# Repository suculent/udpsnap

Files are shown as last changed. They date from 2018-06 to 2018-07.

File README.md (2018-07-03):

# UDP Snap

[See video](https://www.youtube.com/watch?v=fNixYq2eqGM&feature=youtu.be&a=)

Aim of this project is to provide iOS camera capture triggered by UDP commands from remote device.
In this example an ESP-8266 based rotary pad with H-L293N bridge, HS17 servo and some 3D printed parts.

## ESP8266

App for ESP8266 controls servo by advancing given steps in given interval, which is not exact in order to prevent vibrations.
Posts notifications on steps, so the iOS camera knows when is the right time to capture numbered step.

## iOS

* Minimal app in Swift 4 for iOS 11+, features latest photo capture APIs and server built on IBM's BlueSocket framework.
* App starts UDP server and performs camera capture directly to iCloud drive Documents when notified by ESP8266 client.
* UDP commands are received over WiFi from device acquired over MDNS on the same network.
* The communication is bi-directional, sending following commands: `PLAY`, `STOP`, `REWIND`.
* Client app is additionaly able to configure turntable jitter and time-lapse interval using commands `JIT:<Int, millis>` and `INT:<Int, seconds>`.

## Roadmap

* App should be able to reset container and/or order projects in folders in future.

# The Rig

You can find 3D source files in STL format inside the `rig` folder along with original SVGs for wheels. I'm not an industrial designer, so this is first drop, free to refactor.

* There's a known bug in the base where it's not entirely possible to insert servo without cutting a hole in the base. This will be fixed later.

* Also the large cog axis needs to be fastened against servo to fix wheels together safely and prevent skipping a step.

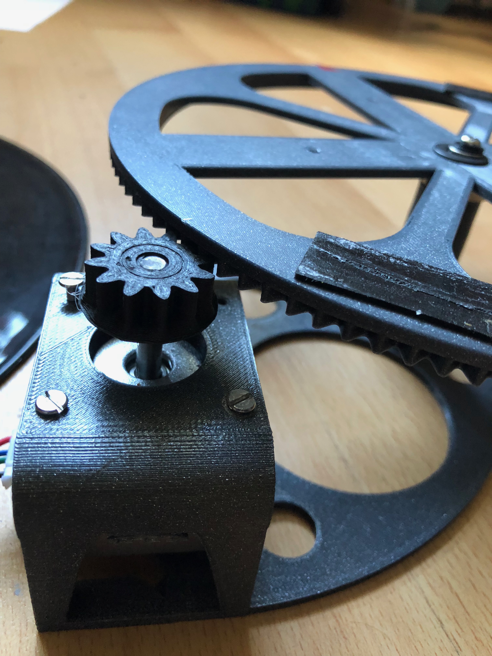
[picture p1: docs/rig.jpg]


# Processing

You can use various tools to process captured photos. There's a new iOS app called Qlone, that works great with this rig... just stick the QR Code Matte to a vinyl record, drop onto the rig and adjust ESP code to make at lease 6 revolutions (Qlone captures not only 360° but also from 4 different side angles, while rendering the result in real time!).

I've been happy with free trial of Agisoft's [PhotoScan](http://www.agisoft.com) for MacOS (supports High Sierra).

For other platforms, you can use [3DF Zephyr](https://www.3dflow.net/3df-zephyr-free/) which is a free solution as well, but did not work on my version of OS X.

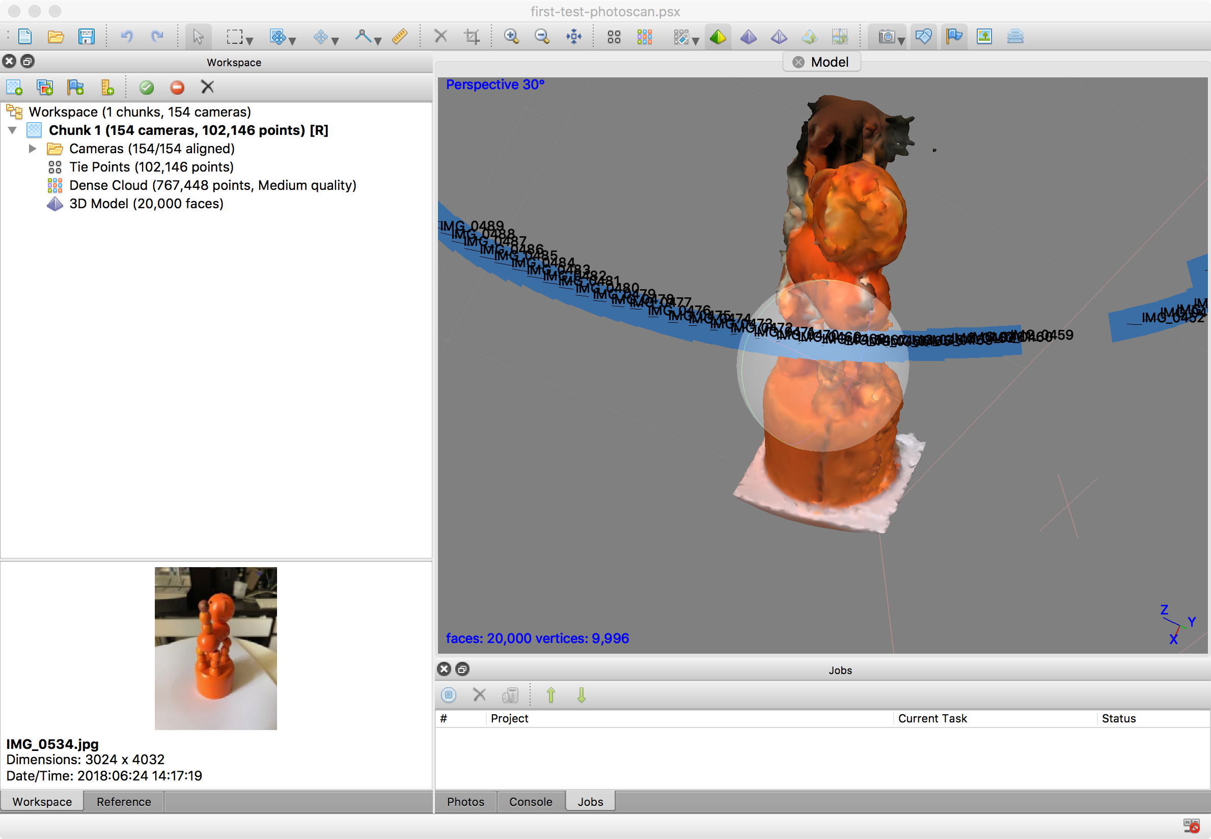
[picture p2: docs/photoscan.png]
PhotoScan


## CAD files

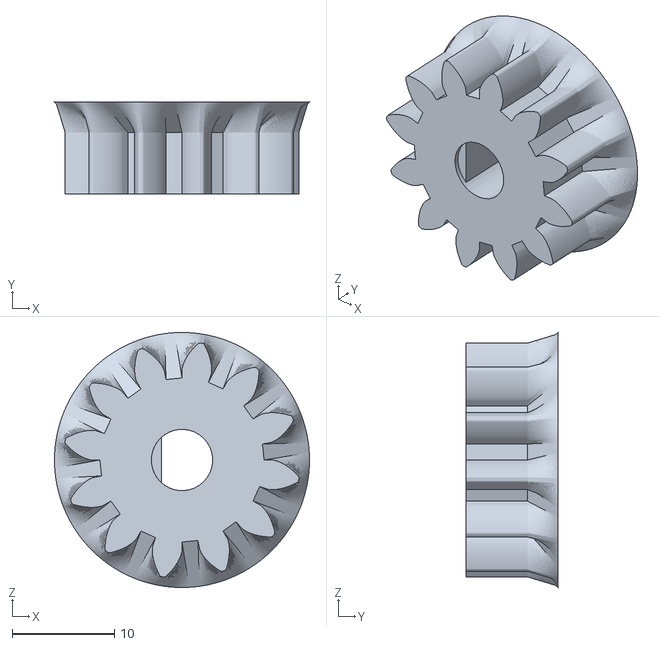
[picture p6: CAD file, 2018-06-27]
rig/Small Cog V3 Filamentum CF15 Carbon.stl
24.9 x 9.00 x 24.9

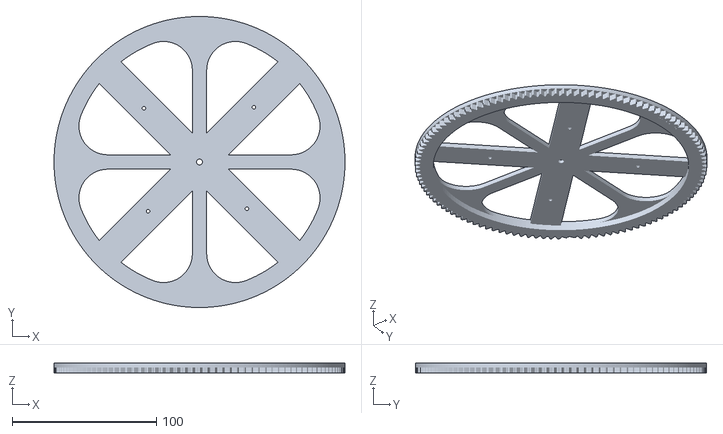
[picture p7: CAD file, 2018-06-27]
rig/Large Cog Filamentum PLA.stl
202.0 x 202.0 x 6.80

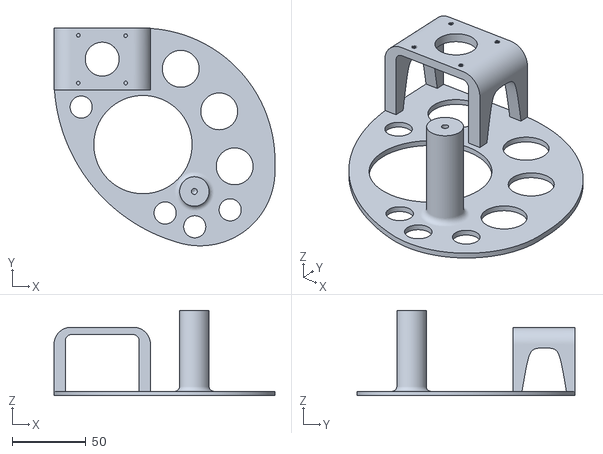
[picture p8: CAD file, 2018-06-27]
rig/Base Filamentum PLA.stl
150.0 x 147.7 x 58.0

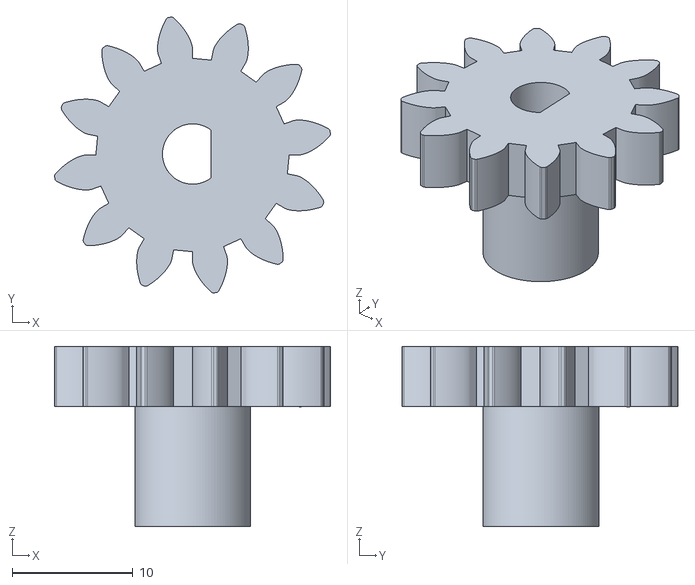
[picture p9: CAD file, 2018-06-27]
rig/Small Cog V2 Filamentum PLA.stl
22.9 x 22.9 x 14.9

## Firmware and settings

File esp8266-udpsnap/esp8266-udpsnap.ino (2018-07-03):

// Wemos D1 with L293N-based motor driver, HS17 motor and 

#include "ESP8266WiFi.h"
#include "WiFiUdp.h"
#include <ESP8266mDNS.h>

// The port can be any integer between 1024 and 65535
const unsigned int NET_PORT = 58266;

WiFiUDP Udp;

const int LED_PIN = D4;

char net_payload[6] = "P:999";

IPAddress clientIP = atoi("192.168.1.18");
int clientPort;

unsigned long interval = 20; // 2000;
int stepcount = 0;
unsigned long start = millis();

char packetBuffer[UDP_TX_PACKET_MAX_SIZE];

char replyBuffer[UDP_TX_PACKET_MAX_SIZE];
char RunningReplyBuffer[] = "RUNNING";       // a string to send back
char StoppedReplyBuffer[] = "STOPPED";       // a string to send back
char RewindReplyBuffer[] = "REWIND";       // a string to send back
char OKReplyBuffer[] = "OK";       // a string to send back


unsigned long jitter = 0; // prevent vibrations

bool isRunning = true;

void udp_broadcast(int index){  

  sprintf(net_payload, "P:%i", index);
  
  /*
   /IPAddress broadcastIP = ~WiFi.subnetMask() | WiFi.gatewayIP();
  
  Udp.beginPacket(broadcastIP, NET_PORT);
  Udp.write(net_payload);
  Udp.endPacket();
  * 
   */

  Serial.println("clientIP");
  Serial.println(clientIP);
  Serial.println("clientPort");
  Serial.println(clientPort);

  if (interval < 100) {
    Udp.beginPacket(clientIP, clientPort);
    Udp.write(net_payload);
    Udp.endPacket();  
  }
}

#include <Stepper.h>

const int stepsPerRevolution = 200;  // 1.8° per step
Stepper myStepper(stepsPerRevolution, D5, D6, D7, D8);

// Max RPM is 40!
unsigned long timeout;
bool ledstate = false;

void setup() {
  Serial.begin(230400);
  Serial.print("PINS: D5, D6, D7, D8");
  myStepper.setSpeed(10); // max seems 100 (percent?)

  WiFi.begin("THiNX-IoT", "<enter-your-ssid-password>");  
  delay(2000);

  int wifi_status;

  if (wifi_status != WL_CONNECTED) {    
    Serial.println(F("Waiting for WiFi connection..."));    
    timeout = millis() + 5000;
    while (millis() < timeout) {
      ledstate = !ledstate;
      digitalWrite(LED_PIN, ledstate);
      delay(500);
      Serial.print(".");
    }
  }

  digitalWrite(LED_PIN, LOW);


  MDNS.begin("rotopad");
  MDNS.addService("rotopad", "udp", NET_PORT);

  Serial.println();
  Serial.println("Performing mDNS query...");
  int n = MDNS.queryService("camera", "udp");
  Serial.println("mDNS query done");
  if (n == 0) {
    Serial.println("No services found.");
  }
  else {
    Serial.print(n);
    Serial.println(" service(s) found");
    for (int i = 0; i < n; ++i) {
      // Take first valid service and bail out
      Serial.print(i + 1);
      Serial.print(": ");
      Serial.print(MDNS.hostname(i));
      Serial.print(" (");
      Serial.print(MDNS.IP(i));
      Serial.print(":");
      Serial.print(MDNS.port(i));
      Serial.println(")");

      clientIP = MDNS.IP(i);
      clientPort = MDNS.port(i);
      break;
    }
  }
  Serial.println();

  Serial.println("Starting UDP server...");
  Udp.begin(NET_PORT);
}



void loop() {

  // Rotate while isRunning is enabled and stepcount < 5 revolutions
  if (isRunning == true) {
    if (stepcount < 10 * 5 * 200) {
      if (timeout < millis()) {
        stepcount++;
        unsigned long jitter_value = random(-jitter, jitter);
        timeout = millis() + interval + jitter_value;  // +10 = 20s/revolution
        digitalWrite(LED_PIN, HIGH);
        myStepper.step(-1);
        digitalWrite(LED_PIN, LOW);
        Serial.printf("step #%i (%u seconds)\n", stepcount, (millis() - start)/1000);
        // Broadcast step count to synchronize camera capture over UDP
        udp_broadcast(stepcount);
      }
    }
  }

  int packetSize = Udp.parsePacket();
  if (packetSize)
  {
    Serial.print("Received packet of size ");
    Serial.println(packetSize);
    Serial.print("From ");
    IPAddress remote = Udp.remoteIP();
    for (int i = 0; i < 4; i++)
    {
      Serial.print(remote[i], DEC);
      if (i < 3)
      {
        Serial.print(".");
      }
    }
    Serial.print(", port ");
    Serial.println(Udp.remotePort());    

    // read the packet into packetBufffer
    Udp.read(packetBuffer, UDP_TX_PACKET_MAX_SIZE);
    Serial.println("Contents:");
    Serial.println(packetBuffer);

    String message = String(packetBuffer);

    Udp.beginPacket(Udp.remoteIP(), Udp.remotePort());

    if (message.indexOf("PLAY") != 1) {      
      Udp.write(RunningReplyBuffer);    
      isRunning = true;  
    }

    if (message.indexOf("STOPPED") != 1) {
      Udp.write(RunningReplyBuffer);
      isRunning = false;
    }

    if (message.indexOf("REWIND") != 1) {
      myStepper.step(-10 * stepcount);
      stepcount = 0;
      Udp.write(RewindReplyBuffer);
    }

    if (message.indexOf("INT:") != 1) {
      String newIntervalString = message;
      newIntervalString.replace("INT:", "");
      interval = newIntervalString.toInt();
      Udp.write(OKReplyBuffer);
    }

    if (message.indexOf("JIT:") != 1) {
      String newJitterString = message;
      newJitterString.replace("INT:", "");
      jitter = newJitterString.toInt();
      Udp.write(OKReplyBuffer);
    }
  }  
}

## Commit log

2018-06-25 initial commit - UDP server, camera capture, saving
2018-06-25 first working version, receives UDP messages from IoT device to trigger photo-capture, saves to device and iCloud container (should be already public)
2018-06-26 show status with regard to device connection
2018-06-26 sending UDP messages to device
2018-06-27 added notification for case where device is not found
2018-06-27 added docs and rig models
    [Base Filamentum PLA.stl, Large Cog Filamentum PLA.stl, Small Cog V2 Filamentum PLA.stl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]
2018-07-03 improved command resolution, added support for interval and jitter
    [esp8266-udpsnap.ino]
